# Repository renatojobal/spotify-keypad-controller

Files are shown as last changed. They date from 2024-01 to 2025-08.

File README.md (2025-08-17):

# Spomacropad | spotify-keypad-controller
> Forked from https://github.com/vergoh/micropython-spotify-status-display

The Spomacropad is a MicroPython implementation for ESP32, featuring a small OLED display to show the "currently playing" information of a Spotify playback device. You can customize it by adding a display, buttons, or a potentiometer according to your preference. For optimal usability, it is highly recommended to include the buttons.

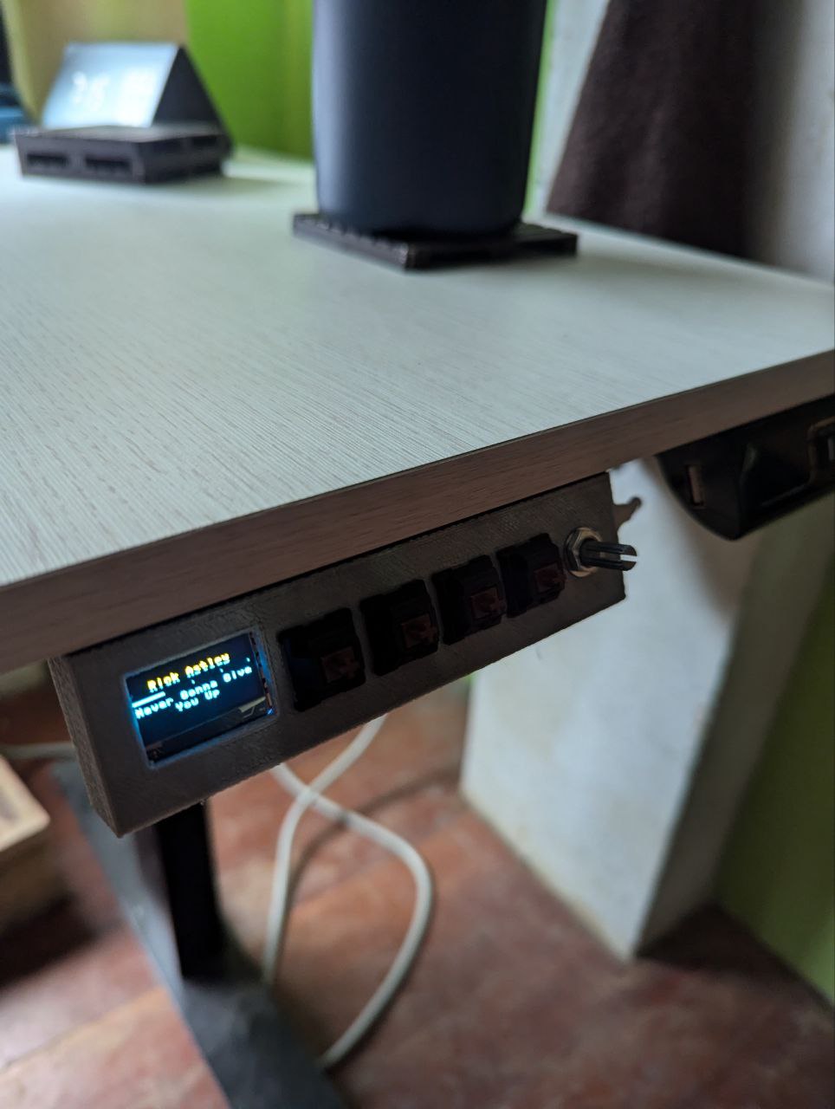
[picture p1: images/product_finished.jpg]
Product finished


## Features

- "currently playing" information with progress bar
  - artist + track
  - show/podcast + episode
- playback control (optional)
  - previous track 
  - play / pause
  - next track
  - pause after current track
  - add current track to library
  - switch device playing
- configurable poll interval and behavior
- access token stored in the device after initial login
- buzzer (optional) for confirming button presses
- screensaver for standby mode
- self-contained implementation
- [custom 3D printable case](stl/case.stl) or custimze the model in [Thinkercad](https://www.tinkercad.com/things/2gLBOgj0QfW-spomacropad)

## Requirements

- ESP32 with [MicroPython](https://micropython.org/) 1.14 or later
  - version 1.18 or later recommended
  - (I had problems with version 1.22, but 1.21 works fine)
- SSD1306, SSD1309, or SSD1315 compatible 128x64 pixel OLED display in I2C mode
  - [0.96" SSD1306](https://www.google.com/search?q=128x64+oled+i2c+0.96+ssd1306)
  - [0.96" SSD1315](https://www.google.com/search?q=128x64+oled+i2c+0.96+ssd1315) (used in the images)
  - [2.42" SSD1309](https://www.google.com/search?q=128x64+oled+i2c+2.42+ssd1309)
  - most likely okay
    - [1.3" SSD1306](https://www.google.com/search?q=128x64+oled+i2c+1.3+ssd1306)
  - not verified
    - [1.3" SH1106](https://www.google.com/search?q=128x64+oled+i2c+1.3+sh1106)
- [4 Cherry MX switches](https://www.google.com/search?q=cherry%20mx%20switch)
- [4 keycaps](https://www.google.com/search?q=cherry%20mx%20switch%20keycaps)
- 1 10k potentiometer
- WLAN connectivity
- Spotify account
  - Premium needed for playback control
- control buttons (optional)
- buzzer (optional)

See also the beginning of [Case.md](Case.md) for a full list of needed components for building the cased solution shown above.

## Limitations

- buttons don't react during API requests / server communication
- buttons require Spotify Premium due to API restrictions
- default font supports mainly US-ASCII characters
  - unsupported Western characters are, however, automatically mapped to the closest US-ASCII equivalents
- playback device isn't aware of the status display, resulting in delayed status changes when the playback device is directly controlled

## TODO

- better handling of rare cases of `ECONNABORTED` followed by `EHOSTUNREACH` which gets displayed
- async API requests / server communication (if possible)

## Building it

- [3D printed case build](Case.md) or [DIY wiring](Wiring.md) explains the hardware setup
- [Configuration](Configuration.md) contains the install instructions

## Controls

| | active, short press | active, long press | standby | 
| --- | --- | --- | --- |
| previous button | previous track | | | 
| stop button | play / pause / resume | save track | wake up and resume playback | 
| next button | next track | pause after current track | wake up |
| switch button | switch playing to another available device | | |
| potentiometer | volume control (when available) | | |

Long press is >= 500 ms by default.

## Included 3rd party implementations

| file | description |
| --- | --- |
| `ssd1306.py` | based on <https://github.com/adafruit/micropython-adafruit-ssd1306> |
| `uurequests.py` | based on <https://github.com/pfalcon/pycopy-lib/blob/master/uurequests/uurequests.py> |
| `helpers.py` | reduced from <https://github.com/blainegarrett/urequests2> |

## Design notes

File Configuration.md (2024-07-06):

# Configuration

## Get Spotify client_id and client_secret

1. Login do [Spotify developer dashboard](https://developer.spotify.com/dashboard/login)
2. Select "Create an app"
3. Fill "Status display" or similar as app name, description can be a link to this project or anything else
4. Click "Edit setting" and add `http://spomacropad.local/callback/` as "Redirect URI"
   - `spomacropad` needs to match the `mdns` name configured in the next section
   - `http://` prefix and `.local/callback/` must remain as shown
5. Save the settings dialog
6. Click "Show client secret" and take note of both "Client ID" and "Client Secret"

## Create and edit src/config.json

1. Create a copy of the file `src/config.json.bk` with the name of `src/config.json`
2. Fill `client_id` and `client_secret` with values acquired in previous step
3. Fill `pins` section according to used wiring
4. Fill `wlan` section, use `mdns` value selected in previous step

## Send implementation and config to device

1. Transfer the implementation using a serial connection with MicroPython command line
   - **Option 1** - direct source files, higher memory usage:
      1. With MicroPython command line, `put` the content of `src` directory to the root of the device
   - **Option 2** - precompiled binaries, lower memory usage but requires extra step:
      1. With `mpy-cross` installed using `pip`, run `make` to compile the binaries
         - The used `mpy-cross` version needs to match used MicroPython release, see [MicroPython documentation](https://docs.micropython.org/en/latest/reference/mpyfiles.html#versioning-and-compatibility-of-mpy-files) for version compatibility details
      2. With MicroPython command line, `put` the content of `target` directory to the root of the device
         - Possible previously installed `.py` files need to be removed before this step when upgrading
2. Start `repl` and soft reset the device with ctrl-d
3. Fix any possible configuration errors based on shown output
4. Login to Spotify using the provided url and accept requested permissions

If a Spotify device doesn't currently have playback active then the display should reflect the situation. Start playback and the display should react to the change within the configured poll interval.

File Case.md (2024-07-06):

# Case

## Required components

- [Lolin32 Lite](https://www.google.com/search?q=Lolin32+Lite)
- [2.42" SSD1309 based OLED](https://www.google.com/search?q=128x64+oled+i2c+2.42+ssd1309)
- 2 x [R13-507](https://www.google.com/search?q=R13-507) push buttons
- 1 x 6V 470 μF capacitor
- 1 x 6V 100 μF capacitor
- 1 x 10 kΩ resistor
- 4 x M2 hex socket head cap screw, 10-12 mm
  - head cap is visible in the front panel, select accordingly, black hex socket works well
- 2 x M2 hex socket head cap screw, 6-8 mm
  - head cap is hidden under the case and can be anything available
- 6 x M2 nut
- 4 x 2x6 or 2x10 screw (metric, for lid)
- single row 2.54 mm male pin header
  - 4 pins for buttons
  - 5 pins for OLED
  - 2 x 8 pins for Lolin32 Lite (may come with it)
- 2 x 8 pin single row 2.54 mm female pin socket
- 1 x 5 pin single row 2.54 mm female pin header connector
  - for OLED
- 2 x 2 pin single row 2.54 mm female pin header connector
  - for buttons
- 1 x piezo buzzer (optional), 9 mm diameter preferably but 13 mm diamater should also fit
- 1 x [4x6 cm double sided prototype pcb](https://www.google.com/search?q=4x6+cm+double+sided+prototype+pcb)
- 28 AWG (or similar size) wire

Additionally some suitable tools, a soldering iron and access to a 3D printer is needed.

## Printing

Print [case.stl](stl/case.stl) using PLA or similar plastic. Use 0.1 - 0.2 mm layer height depending on wanted finish. The case model doesn't need support when printed with the model front facing the bed as shown in the preview. The lid however should be rotated and printed flat.

## OLED I2C setup

The 2.42" SSD1309 based OLED may come by default setup in SPI mode. In that case, the back side of the pcb should look the following:

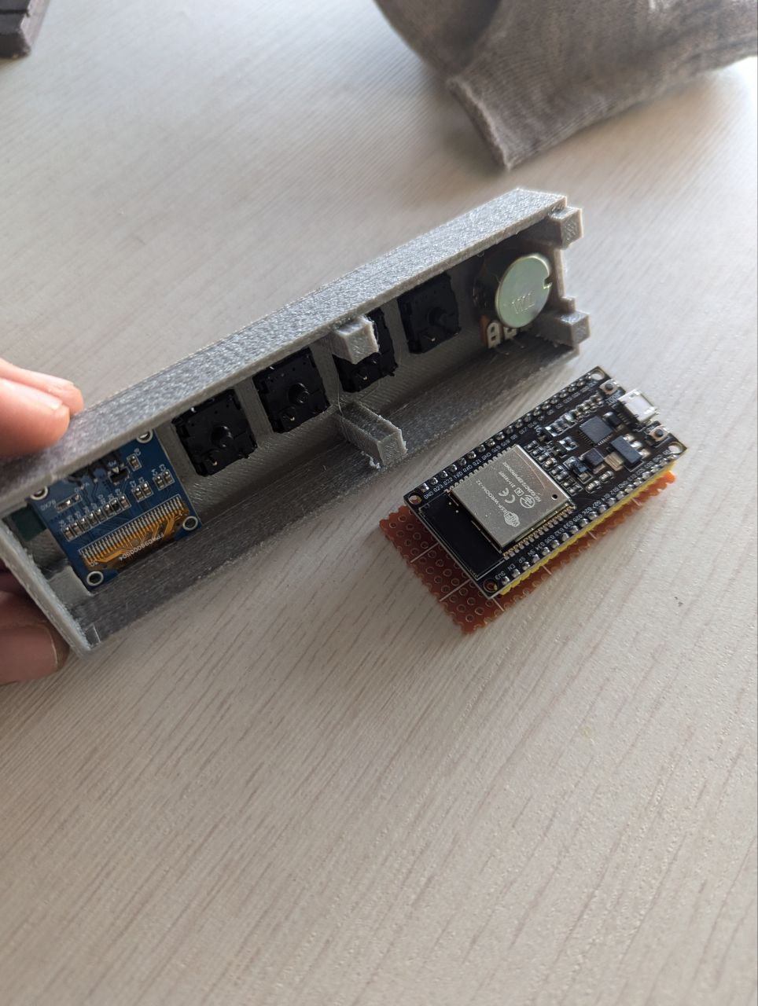
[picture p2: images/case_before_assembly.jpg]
OLED back pcb


For I2C mode, remove the resistor R4 and bridge R3, R5 and R7.

## Assembly

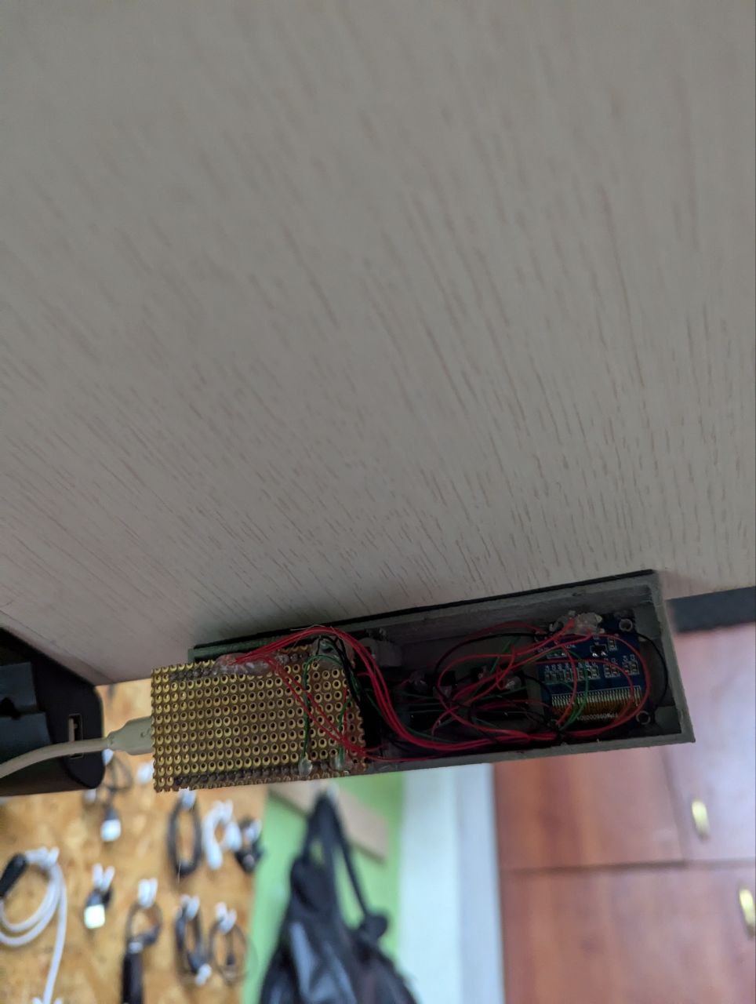
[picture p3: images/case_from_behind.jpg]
Case from behind


1. Clean the case of any excess plastic left after printing.
2. Attach the OLED to the case using the longer M2 screws and nuts. Don't overtighten.
3. Solder pin headers to Lolin32 Lite with pins facing up. If full length pins headers aren't available then start pins from 3V3 and GND on both sides.
4. Attach female pin header connector on top of pin headers from previous step with pins starting from 3V3 on one side and GND on the other side.
5. Place 4x6 cm prototype pcb on top of female pin header connectors and center the board. The unused empty line should be on the side of the USB connector. Solder the female pin header connectors to the pcb.
6. Wire PCB connections according to below image. Keep the components height low when possible. The 100 μF capacitor should be set on its side while the 470 μF capacitor can stay upright even if built further back than shown in the image. Wires for OLED connector (shown as pin header in the image) can be soldered to connect directly to the source pins or other available locations. Connecting the piezo buzzer shown near the 470 μF capacitor is optional.
7. Attach Lolin32 Lite board without the prototype pcb on top of it to the case using the shorter M2 screws / nuts.
8. Connect the display connector from the prototype pcb to the connector on the OLED and attach the prototype pcb on top of Lolin32 lite.
9. Solder wires with connectors to push buttons, make the solder connections face sideways instead of directly down.
10. Attach the push buttons to the case and connect the wires to the prototype pcb.
11. Visually inspect the end result for possible bad connections or extra parts and shake the case to check nothing is loose.
12. Screw the back lid close.

Continue with [Configuration](Configuration.md).

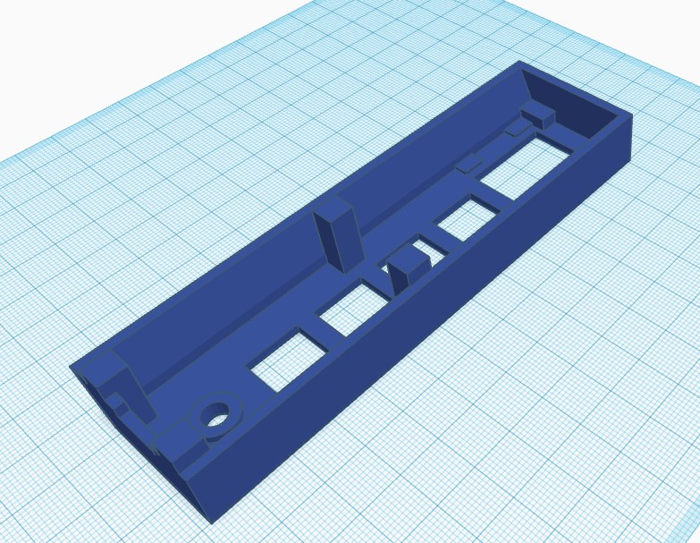
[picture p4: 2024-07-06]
images/prototype.jpg

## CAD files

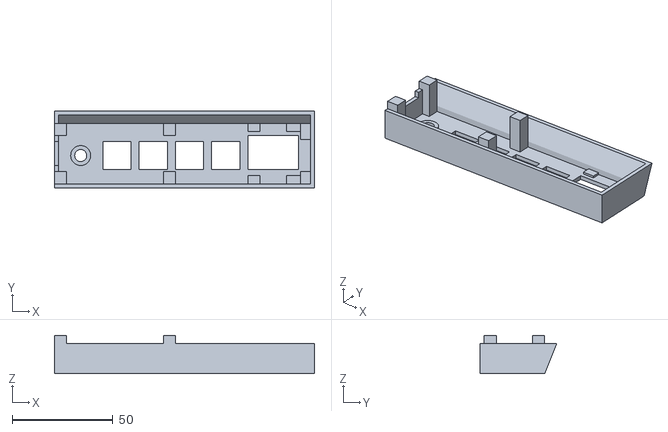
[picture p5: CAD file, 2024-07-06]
stl/case.stl
129.0 x 38.0 x 19.0

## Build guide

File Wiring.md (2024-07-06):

# Wiring

See the live scheme here:
https://www.flux.ai/renatojobal/spomacropadopensource?editor=schematic
Example connections for "Lolin32 Lite" pins using a SSD1306 based OLED. Pins may vary on other ESP32 boards. For case build, see [Case.md](Case.md).

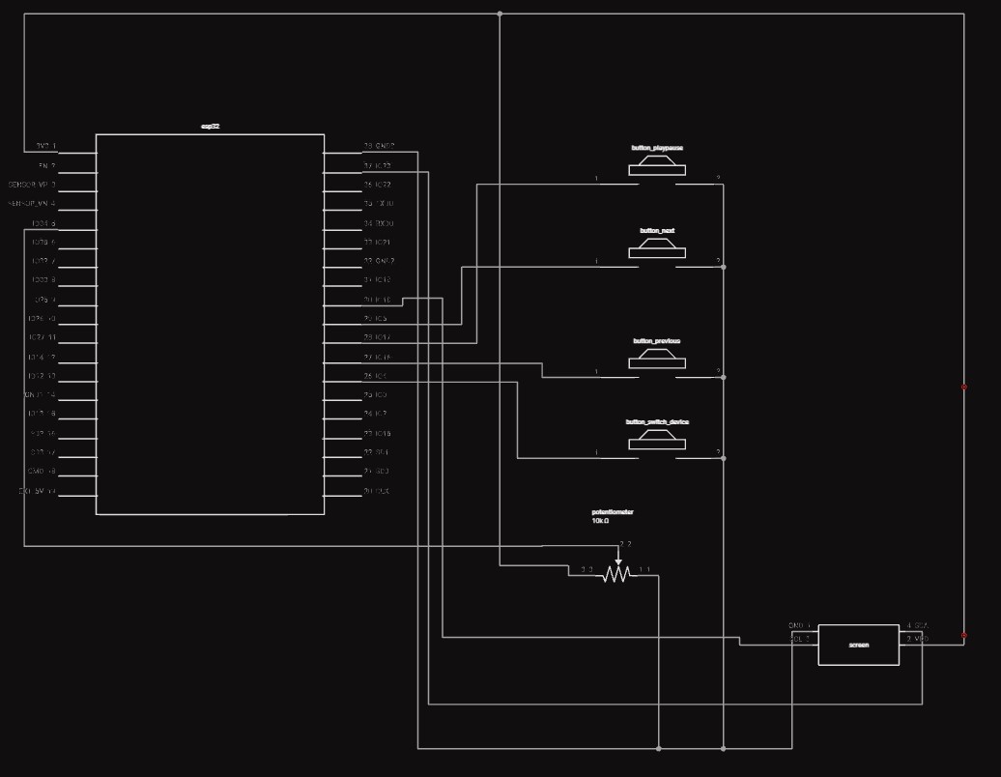
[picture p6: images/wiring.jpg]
Wiring Diagram


## SSD1306 OLED

For 0.96" and 1.3" OLEDs using the SSD1306 chip in i2c mode.

| ESP32 | OLED |
| --- | --- |
| 3V3 | VCC |
| GND | GND |
| 23 | SDA |
| 18 | SCK |

## SSD1309 OLED

For 2.42" OLEDs using the SSD1309 chip in i2c mode, use the same wiring as for the SSD1306 OLED shown above. Note that most of these SSD1309 OLEDs require resistors to be moved for enabling the i2c mode. Additionally, a capacitor of around 220-470 μF is needed between ESP32 3V3 and GND in order to avoid brownout during wlan startup when OLED is being active at the same time. This issue can be seen as a "Brownout detector was triggered" console message followed by a forced reset. Also OLED RES needs to be connected to OLED VCC using a 10 kΩ resistor and to GND using a 10-100 μF capacitor:

| OLED | component | OLED |
| --- | --- | ---
| RES | 10 kΩ resistor | VCC |
| RES | 10-100 μF capacitor | GND |

## Buttons

| ESP32 | button | ESP32 |
| --- | --- | --- |
| D4 | left button | GND |
| D5 | right button | GND |

Button pins need to support internal pullups.

## Piezo Buzzer (Optional)

| ESP32 | Buzzer |
| --- | --- |
| 27 | VCC |
| GND | GND |

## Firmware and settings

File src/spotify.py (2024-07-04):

# MIT License
# Copyright (c) 2020 Teemu Toivola
# https://github.com/vergoh/micropython-spotify-status-display

import gc
import time
import ujson
import network
import uasyncio as asyncio
from machine import Pin
from micropython import const, mem_info

# imports from additional files
import oled
import spotify_api
from buttonpress_async import button_async
from buzzer import buzzer
from potenciometer_async import potenciometer_async

_app_name = const("Spotify status")

class Spotify:

    def __init__(self):
        self.device_id = None
        self.available_devices = []  # Used to switch functionality
        self.used_devices = []  # Used to switch functionality
        self.pause_after_current = False
        self._set_memory_debug()
        self.config = {}
        with open('config.json', 'r') as f:
            self.config = ujson.load(f)

        if self.config['use_led']:
            self.led = Pin(self.config['pins']['led'], Pin.OUT)
            for v in [1, 0, 1]:
                self.led.value(v)
                time.sleep_ms(100)
            self.led.value(0)

        if self.config['use_display']:
            self.oled = oled.OLED(scl_pin = self.config['pins']['scl'], sda_pin = self.config['pins']['sda'], contrast = self.config['contrast'])
            if self.config['low_contrast_mode']:
                self.oled.oled.precharge(0x22)
        else:
            self.oled = oled.OLED(enable = False)
        self.oled.show(_app_name, "__init__", separator = False)

        self._validate_config()

        if self.config['use_buzzer']:
            self.buzzer = buzzer(Pin(self.config['pins']['buzzer'], Pin.OUT), frequency = self.config['buzzer_frequency'], duty = self.config['buzzer_duty'])
            self.buzzer.buzz()
        else:
            self.buzzer = None

        if not self.config['spotify'].get('client_id') or not self.config['spotify'].get('client_secret'):
            self.oled.show(_app_name, "client not configured", separator = False)
            raise RuntimeError("client_id and/or client_secret not configured")

        self.button_playpause = button_async(Pin(self.config['pins']['button_playpause'], Pin.IN, Pin.PULL_UP), long_press_duration_ms = self.config['long_press_duration_milliseconds'], buzzer = self.buzzer)
        self.button_next = button_async(Pin(self.config['pins']['button_next'], Pin.IN, Pin.PULL_UP), long_press_duration_ms = self.config['long_press_duration_milliseconds'], buzzer = self.buzzer)
        self.button_previous = button_async(Pin(self.config['pins']['button_previous'], Pin.IN, Pin.PULL_UP), long_press_duration_ms = self.config['long_press_duration_milliseconds'], buzzer = self.buzzer)
        self.button_switch_device = button_async(Pin(self.config['pins']['button_switch_device'], Pin.IN, Pin.PULL_UP), long_press_duration_ms = self.config['long_press_duration_milliseconds'], buzzer = self.buzzer)
        if self.config['use_potentiometer']:
            self.button_volume_control = potenciometer_async(self.config['pins']['potentiometer_volume_control'], enable = True)
        else:
            self.button_volume_control = potenciometer_async(self.config['pins']['potentiometer_volume_control'], enable = False)

        print("buttons enabled")

        if self.config['setup_network']:
            self.wlan_ap = network.WLAN(network.AP_IF)
            self.wlan_ap.active(False)
            self.wlan = network.WLAN(network.STA_IF)
            try:
                self.wlan.active(True)
                self.wlan.connect(self.config['wlan']['ssid'], self.config['wlan']['password'])
                self.wlan.config(dhcp_hostname=self.config['wlan']['mdns'])
            except Exception as e:
                self.oled.show(e.__class__.__name__, str(e))
                if str(e) == "Wifi Internal Error":
                    time.sleep(3)
                    import machine
                    machine.reset()
                else:
                    raise
            print("network configured")
        else:
            self.wlan = network.WLAN()
            print("using existing network configuration")

        if self.config['enable_webrepl']:
            import webrepl
            webrepl.start()

        self._wait_for_connection()

        self.ip = self.wlan.ifconfig()[0]
        self.redirect_uri = "http://{}.local/callback/".format(self.config['wlan']['mdns'])

        self.oled.show(_app_name, "__init__ connected {}".format(self.ip), separator = False)
        print("connected at {} as {}".format(self.ip, self.config['wlan']['mdns']))

    def _set_memory_debug(self):
        import os
        self.memdebug = False

        try:
            if os.stat("memdebug") != 0:
                self.memdebug = True
        except Exception:
            pass

        if self.memdebug:
            print("memory debug enabled")
        else:
            print("no \"memdebug\" file or directory found, memory debug output disabled")

    def _validate_config(self):
        boolean_entries = const("use_display,use_led,use_buzzer,setup_network,enable_webrepl,show_progress_ticks,low_contrast_mode,blank_oled_on_standby")
        integer_entries = const("contrast,status_poll_interval_seconds,standby_status_poll_interval_minutes,idle_standby_minutes,long_press_duration_milliseconds,api_request_dot_size,buzzer_frequency,buzzer_duty")
        dict_entries = const("spotify,pins,wlan")
        spotify_entries = const("client_id,client_secret")
        pin_entries = const("led,scl,sda,button_playpause,button_next,buzzer")
        wlan_entries = const("ssid,password,mdns")

        for b in boolean_entries.split(','):
            if b not in self.config or type(self.config[b]) is not bool:
                self._raise_config_error("\"{}\" not configured or not boolean".format(b))

        for i in integer_entries.split(','):
            if i not in self.config or type(self.config[i]) is not int:
                self._raise_config_error("\"{}\" not configured or not integer".format(i))

        for d in dict_entries.split(','):
            if d not in self.config or type(self.config[d]) is not dict:
                self._raise_config_error("\"{}\" not configured or not dict".format(d))

        for s in spotify_entries.split(','):
            if s not in self.config['spotify'] or self.config['spotify'][s] is None or len(self.config['spotify'][s]) < 16:
                self._raise_config_error("\"{}\" not configured or is invalid".format(s))

        for p in pin_entries.split(','):
            if p not in self.config['pins'] or type(self.config['pins'][p]) is not int:
                self._raise_config_error("\"{}\" not configured or is invalid".format(p))

        for w in wlan_entries.split(','):
            if w not in self.config['wlan'] or self.config['wlan'][w] is None or len(self.config['wlan'][w]) < 1:
                self._raise_config_error("\"{}\" not configured or is invalid".format(w))
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

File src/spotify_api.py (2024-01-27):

# MIT License
# Copyright (c) 2020 Teemu Toivola
# https://github.com/vergoh/micropython-spotify-status-display

import gc
import time
from micropython import const

# imports from additional files
import uurequests as requests
from helpers import b64encode, urlencode

_spotify_account_api_base = const("https://accounts.spotify.com/api")
_spotify_api_base = const("https://api.spotify.com")

def _spotify_api_request(method, url, data = None, headers = None, retry = True):
    ret = {'status_code': 0, 'json': {}, 'text': 'No reply content'}
    print("{} {}".format(method, url))
    try:
        r = requests.request(method, url, data = data, headers = headers)
    except OSError as e:
        print("OSError: {}".format(e))
        ret['text'] = str(e)
        r = None

    if r is None or r.status_code < 200 or r.status_code >= 500:
        if retry:
            if r is None:
                print("failed, retrying...")
            elif r is not None:
                print("status {}, retrying...".format(r.status_code))
                r.close()
                del r
            time.sleep_ms(500)
            return _spotify_api_request(method, url, data = data, headers = headers, retry = False)
        else:
            return ret

    ret['status_code'] = r.status_code
    try:
        ret['json'] = r.json()
    except Exception as e:
        if r.status_code == 200 and method == "GET":
            print("json decoding failed: {}".format(e))
            if retry:
                if r is not None:
                    r.close()
                    del r
                print("retrying...")
                time.sleep_ms(500)
                gc.collect()
                return _spotify_api_request(method, url, data = data, headers = headers, retry = False)
            ret['status_code'] = 0
            ret['json'] = {'exception': 1}
            ret['text'] = str(e)

    if len(ret['json']) == 0:
        try:
            ret['text'] = r.text
        except:
            pass

    try:
        r.close()
    except:
        pass

    del r
    return ret

def get_api_tokens(authorization_code, redirect_uri, client_id, client_secret):
    spotify_token_api_url = "{}/token".format(_spotify_account_api_base)
    reqdata = { 'grant_type': 'authorization_code', 'code': authorization_code, 'redirect_uri': redirect_uri }

    b64_auth = "Basic {}".format(b64encode(b"{}:{}".format(client_id, client_secret)).decode())
    headers = { 'Content-Type': 'application/x-www-form-urlencoded', 'Authorization': b64_auth }

    return _spotify_api_request("POST", spotify_token_api_url, data = urlencode(reqdata), headers = headers)

def refresh_access_token(api_tokens, client_id, client_secret):
    spotify_token_api_url = "{}/token".format(_spotify_account_api_base)
    reqdata = { 'grant_type': 'refresh_token', 'refresh_token': api_tokens['refresh_token'] }

    b64_auth = "Basic {}".format(b64encode(b"{}:{}".format(client_id, client_secret)).decode())
    headers = { 'Content-Type': 'application/x-www-form-urlencoded', 'Authorization': b64_auth }

    return _spotify_api_request("POST", spotify_token_api_url, data = urlencode(reqdata), headers = headers)

def get_currently_playing(api_tokens):
    spotify_player_api_url = "{}/v1/me/player/currently-playing?additional_types=track,episode".format(_spotify_api_base)
    headers = { 'Authorization': "Bearer {}".format(api_tokens['access_token']) }

    return _spotify_api_request("GET", spotify_player_api_url, headers = headers)

def get_current_device_id(api_tokens):
    spotify_player_api_url = "{}/v1/me/player".format(_spotify_api_base)
    headers = { 'Authorization': "Bearer {}".format(api_tokens['access_token']) }

    return _spotify_api_request("GET", spotify_player_api_url, headers = headers)

def pause_playback(api_tokens):
    spotify_player_api_url = "{}/v1/me/player/pause".format(_spotify_api_base)
    headers = { 'Authorization': "Bearer {}".format(api_tokens['access_token']) }

    return _spotify_api_request("PUT", spotify_player_api_url, headers = headers)

def resume_playback(api_tokens, device_id = None):
    spotify_player_api_url = "{}/v1/me/player/play".format(_spotify_api_base)
    headers = { 'Authorization': "Bearer {}".format(api_tokens['access_token']) }
    if device_id is not None:
        spotify_player_api_url += "?device_id={}".format(device_id)

    return _spotify_api_request("PUT", spotify_player_api_url, headers = headers)

def next_playback(api_tokens, device_id = None):
    spotify_player_api_url = "{}/v1/me/player/next".format(_spotify_api_base)
    headers = { 'Authorization': "Bearer {}".format(api_tokens['access_token']) }
    if device_id is not None:
        spotify_player_api_url += "?device_id={}".format(device_id)

    return _spotify_api_request("POST", spotify_player_api_url, headers = headers)

def previous_playback(api_tokens, device_id = None):
    spotify_player_api_url = "{}/v1/me/player/previous".format(_spotify_api_base)
    headers = { 'Authorization': "Bearer {}".format(api_tokens['access_token']) }
    if device_id is not None:
        spotify_player_api_url += "?device_id={}".format(device_id)

    return _spotify_api_request("POST", spotify_player_api_url, headers = headers)


def get_available_devices(api_tokens):
    spotify_player_api_url = "{}/v1/me/player/devices".format(_spotify_api_base)
    headers = { 'Authorization': "Bearer {}".format(api_tokens['access_token']) }

    return _spotify_api_request("GET", spotify_player_api_url, headers = headers)


def transfer_playback(api_tokens, device_id = None):
    spotify_player_api_url = "{}/v1/me/player".format(_spotify_api_base)
    headers = { 'Authorization': "Bearer {}".format(api_tokens['access_token']), 'Content-Type': 'application/json' }
    if device_id is not None:
        data = "{\"device_ids\":[\""+device_id+"\"]}"
        return _spotify_api_request(method="PUT", url=spotify_player_api_url, data=data, headers = headers, retry=False)


def set_volume_playback(api_tokens, volume=0):
    spotify_player_api_url = f"{_spotify_api_base}/v1/me/player/volume?volume_percent={volume}"
    headers = { 'Authorization': "Bearer {}".format(api_tokens['access_token']) }

    return _spotify_api_request("PUT", spotify_player_api_url, headers = headers)


def save_track(api_tokens, track_id):
    spotify_me_api_url = "{}/v1/me/tracks?ids={}".format(_spotify_api_base, track_id)
    headers = { 'Authorization': "Bearer {}".format(api_tokens['access_token']) }

    return _spotify_api_request("PUT", spotify_me_api_url, headers = headers)

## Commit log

2024-01-18 🎨 create media functions
2024-01-18 🎨 connect spotify functions with api request
2024-01-27 :art: program function to switch devices
2024-06-23 🎨 use more effective configuration
2024-07-04 📝 update README.md
2024-07-04 📝 update Wiring.md
2024-07-06 :memo: update docs
    [case.stl, lid.stl]
